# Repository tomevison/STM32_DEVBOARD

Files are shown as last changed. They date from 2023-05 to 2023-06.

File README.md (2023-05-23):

# STM32_DEVBOARD
Development board for STM32 microcontroller

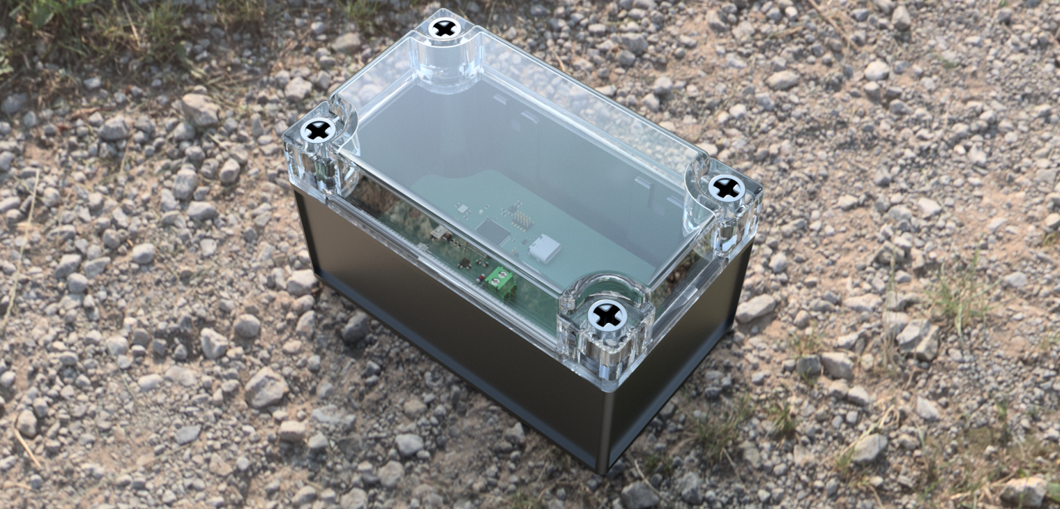
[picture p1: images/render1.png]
Render of Board in Enclosure


Board features a STM32F401RCT6 MCU with a number of peripherals.
- Temperature Humidity Pressure Sensor (Bosch BME280)
- Triple Axis Accelerometer (ST LIS2DW12)
- Tactile Button
- User LED
- USB-C COM Port
- 4-30 VDC input range

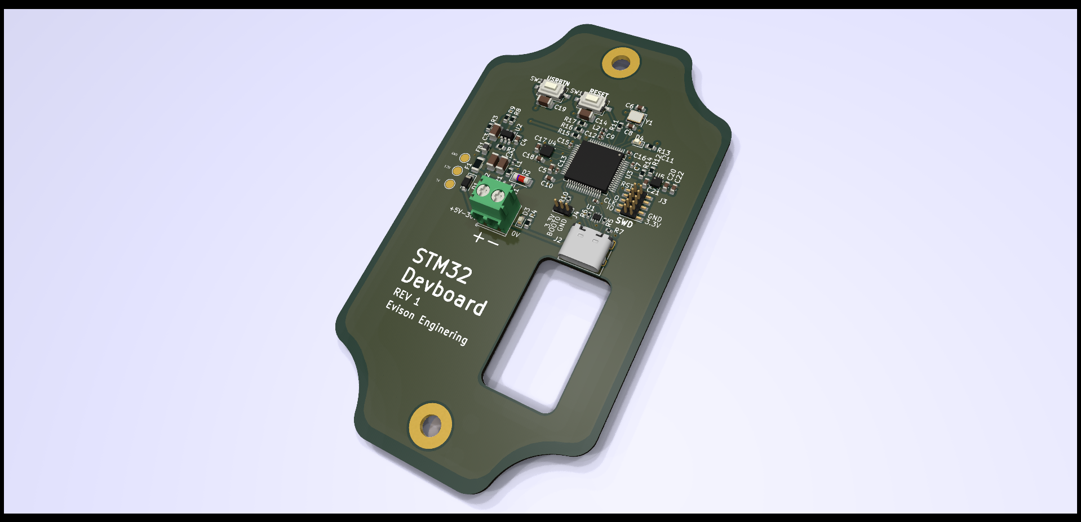
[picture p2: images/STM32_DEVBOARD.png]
Render of PCB


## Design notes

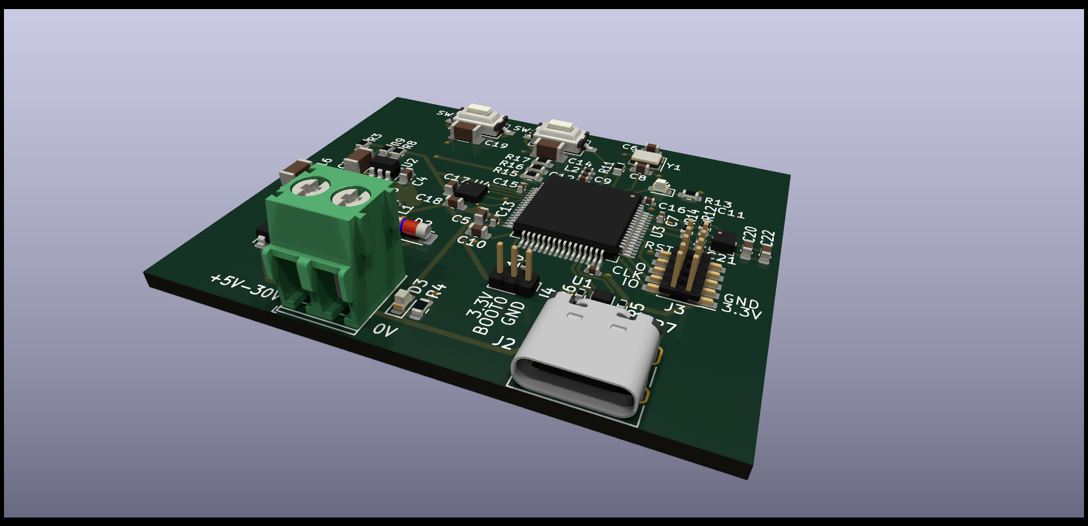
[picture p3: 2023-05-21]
images/devboard_render.png

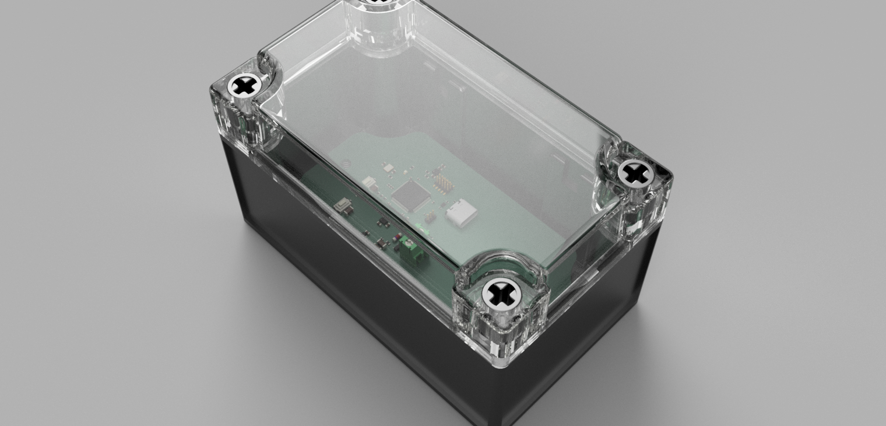
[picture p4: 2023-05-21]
images/Assemb v2.png

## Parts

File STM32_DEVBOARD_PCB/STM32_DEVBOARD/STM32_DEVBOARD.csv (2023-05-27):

# | Reference | Qty | Value | Footprint | DNP
1 | BZ1 | 1 | Buzzer | Buzzer_Beeper:MagneticBuzzer_CUI_CST-931RP-A
2 | C1, C2, C3 | 3 | 10u | Capacitor_SMD:C_1206_3216Metric
3 | C4 | 1 | 10n | Capacitor_SMD:C_0603_1608Metric
4 | C5, C10 | 2 | 4u7 | Capacitor_SMD:C_0603_1608Metric
5 | C6, C8 | 2 | 10p | Capacitor_SMD:C_0603_1608Metric
6 | C7, C11, C13, C15, C16 | 5 | 100n | Capacitor_SMD:C_0402_1005Metric
7 | C9 | 1 | 1u | Capacitor_SMD:C_0402_1005Metric
8 | C12 | 1 | 10n | Capacitor_SMD:C_0402_1005Metric
9 | C14, C19 | 2 | 0u1 | Capacitor_SMD:C_1206_3216Metric
10 | C17, C18, C20, C21 | 4 | 100n | Capacitor_SMD:C_0603_1608Metric
11 | C22 | 1 | 10u | Capacitor_SMD:C_0603_1608Metric
12 | D1 | 1 | B5819W | Diode_SMD:D_SOD-123
13 | D2 | 1 | ZMM5V6-M | Diode_SMD:D_MiniMELF
14 | D3, D4 | 2 | GRN | LED_SMD:LED_0603_1608Metric
15 | F1 | 1 | 250mA | Fuse:Fuse_1206_3216Metric
16 | FB1 | 1 | 600 @ 600MHz | Inductor_SMD:L_0805_2012Metric
17 | H1, H2 | 2 | MountingHole | MountingHole:MountingHole_4.3mm_M4_Pad
18 | J1 | 1 | Screw_Terminal_01x02 | TerminalBlock_Phoenix:TerminalBlock_Phoenix_PT-1,5-2-3.5-H_1x02_P3.50mm_Horizontal
19 | J2 | 1 | USB_C_Receptacle_USB2.0 | Connector_USB:USB_C_Receptacle_HRO_TYPE-C-31-M-12
20 | J3 | 1 | SWD | Connector_PinHeader_1.27mm:PinHeader_2x05_P1.27mm_Vertical_SMD
21 | J4 | 1 | Conn_01x03_Pin | Connector_PinHeader_1.27mm:PinHeader_1x03_P1.27mm_Vertical
22 | L1 | 1 | 4.7u | Inductor_SMD:L_0603_1608Metric
23 | L2 | 1 | 39n | Inductor_SMD:L_0402_1005Metric
24 | Q1 | 1 | AO3401A | Package_TO_SOT_SMD:SOT-23
25 | Q3 | 1 | MMBT3904 | Package_TO_SOT_SMD:SOT-23
26 | R1, R2 | 2 | 100k | Resistor_SMD:R_0603_1608Metric
27 | R3 | 1 | 68k | Resistor_SMD:R_0603_1608Metric
28 | R4, R11, R13 | 3 | R47 | Resistor_SMD:R_0603_1608Metric
29 | R5 | 1 | 1k5 | Resistor_SMD:R_0402_1005Metric
30 | R6, R7 | 2 | 5k1 | Resistor_SMD:R_0402_1005Metric
31 | R8 | 1 | 30k | Resistor_SMD:R_0603_1608Metric
32 | R9, R10, R12, R14, R17 | 5 | 10k | Resistor_SMD:R_0603_1608Metric
33 | R15 | 1 | 220k | Resistor_SMD:R_0603_1608Metric
34 | R16 | 1 | 22k | Resistor_SMD:R_0603_1608Metric
35 | R18 | 1 | 1k | Resistor_SMD:R_0603_1608Metric
36 | SW1 | 1 | BTN_RSET | STM32DEVBOARD:SW_Tactile_SPST_NO_Straight_CK_PTS636-SK25J-SMTR-LFS
37 | SW2 | 1 | BTN1 | STM32DEVBOARD:SW_Tactile_SPST_NO_Straight_CK_PTS636-SK25J-SMTR-LFS
38 | TP1 | 1 | GND | TestPoint:TestPoint_Pad_D2.0mm
39 | TP2 | 1 | 3.3V | TestPoint:TestPoint_Pad_D2.0mm
40 | TP3 | 1 | 5V | TestPoint:TestPoint_Pad_D2.0mm
41 | TP4 | 1 | 24V | TestPoint:TestPoint_Pad_D2.0mm
42 | U1 | 1 | USBLC6-2P6 | Package_TO_SOT_SMD:SOT-666
43 | U2 | 1 | TPMP2359DJ | Package_TO_SOT_SMD:SOT-23-6
44 | U3 | 1 | STM32F401RCTx | Package_QFP:LQFP-64_10x10mm_P0.5mm
45 | U4 | 1 | BME280 | Package_LGA:Bosch_LGA-8_2.5x2.5mm_P0.65mm_ClockwisePinNumbering
46 | U5 | 1 | LIS2DW12 | Package_LGA:LGA-12_2x2mm_P0.5mm
47 | Y1 | 1 | 16MHz | Crystal:Crystal_SMD_3225-4Pin_3.2x2.5mm

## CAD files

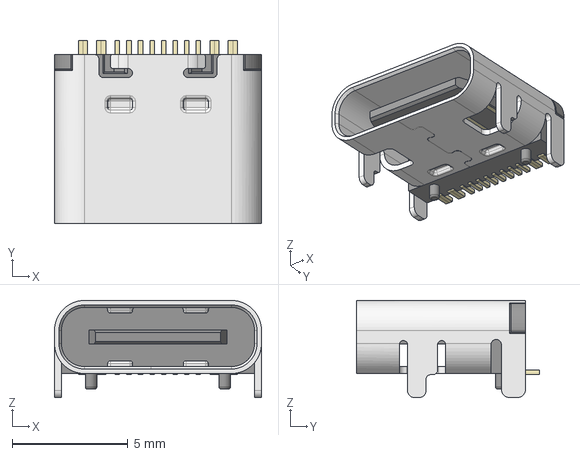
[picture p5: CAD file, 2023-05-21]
STM32_DEVBOARD_PCB/Component Models/USB_HRO_TYPE-C-31-M-12.step
8.95 x 7.90 x 4.20 mm

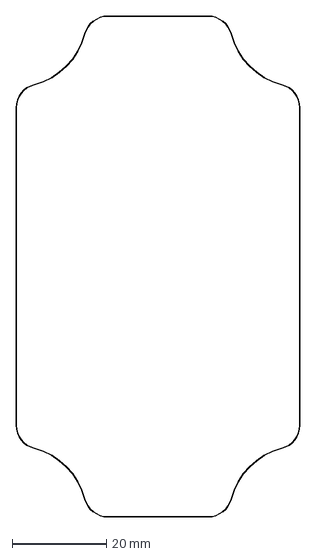
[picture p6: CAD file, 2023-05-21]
STM32_DEVBOARD_PCB/STM32_DEVBOARD/BoardOutline.dxf
60.0 x 106.0 mm

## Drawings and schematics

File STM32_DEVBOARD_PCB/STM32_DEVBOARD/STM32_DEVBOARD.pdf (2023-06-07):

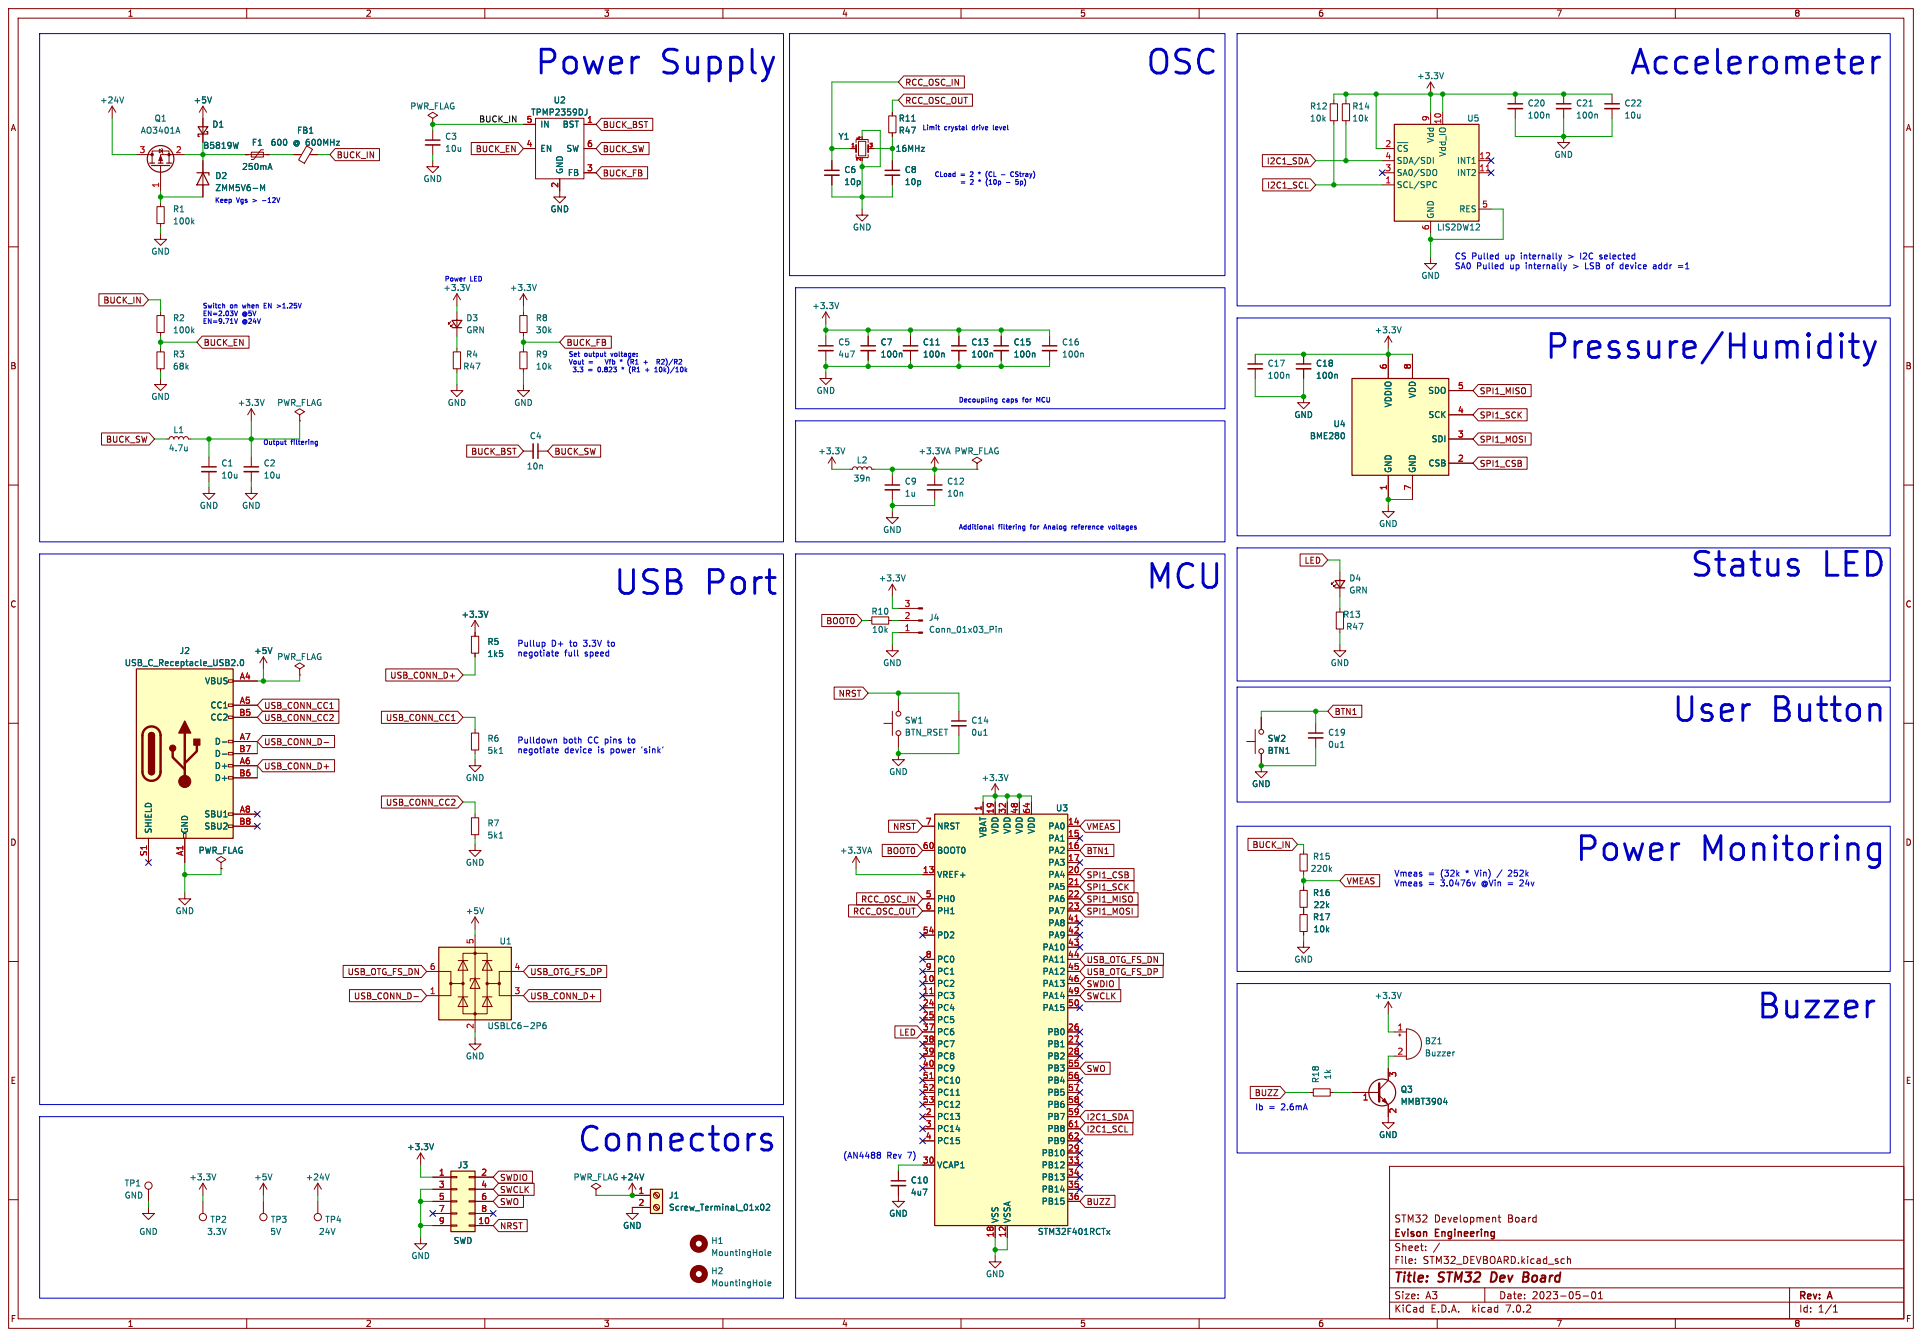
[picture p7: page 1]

BUCK_IN
Keep Vgs > -12V Output filtering Switch on when EN >1.25V

1 CSB 2 SDI 3 SCK 4 SDO 5 VDDIO

Pulldown both CC pins to

1 PC2 10 PC3 11 VSSA 12 VREF+ 13 PA0 14 PA1 15 PA2 16 PA3 17 VSS 18 VDD 19 PC13 2 PA4 20 PA5 21 PA6 22 PA7 23 PC4 24 PC5 25 PB0 26 PB1 27 PB2 28 PB10 29 PC14 3 VCAP1 30 VDD 32 PB12 33 PB13 34 PB14 35 PB15 36 PC6 37 PC7 38 PC8 39 PC15 4 PC9 40 PA8 41 PA9 42 PA10 43 PA11 44 PA12 45 PA13 46 VDD 48 PA14 49 PH0 5 PA15 50 PC10 51 PC11 52 PC12 53 PD2 54 PB3 55 PB4 56 PB5 57 PB6 58 PB7 59 PH1 6 BOOT0 60 PB8 61 PB9 62 VDD 64 NRST 7 PC0 8 PC1 9 U3 STM32F401RCTx GND

1 PC2 10 PC3 11 VSSA 12 VREF+ 13 PA0 14 PA1 15 PA2 16 PA3 17 VSS 18 VDD 19 PC13 2 PA4 20 PA5 21 PA6 22 PA7 23 PC4 24 PC5 25 PB0 26 PB1 27 PB2 28 PB10 29 PC14 3 VCAP1 30 VDD 32 PB12 33 PB13 34 PB14 35 PB15 36 PC6 37 PC7 38 PC8 39 PC15 4 PC9 40 PA8 41 PA9 42 PA10 43 PA11 44 PA12 45 PA13 46 VDD 48 PA14 49 PH0 5 PA15 50 PC10 51 PC11 52 PC12 53 PD2 54 PB3 55 PB4 56 PB5 57 PB6 58 PB7 59 PH1 6 BOOT0 60 PB8 61 PB9 62 VDD 64 NRST 7 PC0 8 PC1 9 C10

Id: 1/1 Title: STM32 Dev Board

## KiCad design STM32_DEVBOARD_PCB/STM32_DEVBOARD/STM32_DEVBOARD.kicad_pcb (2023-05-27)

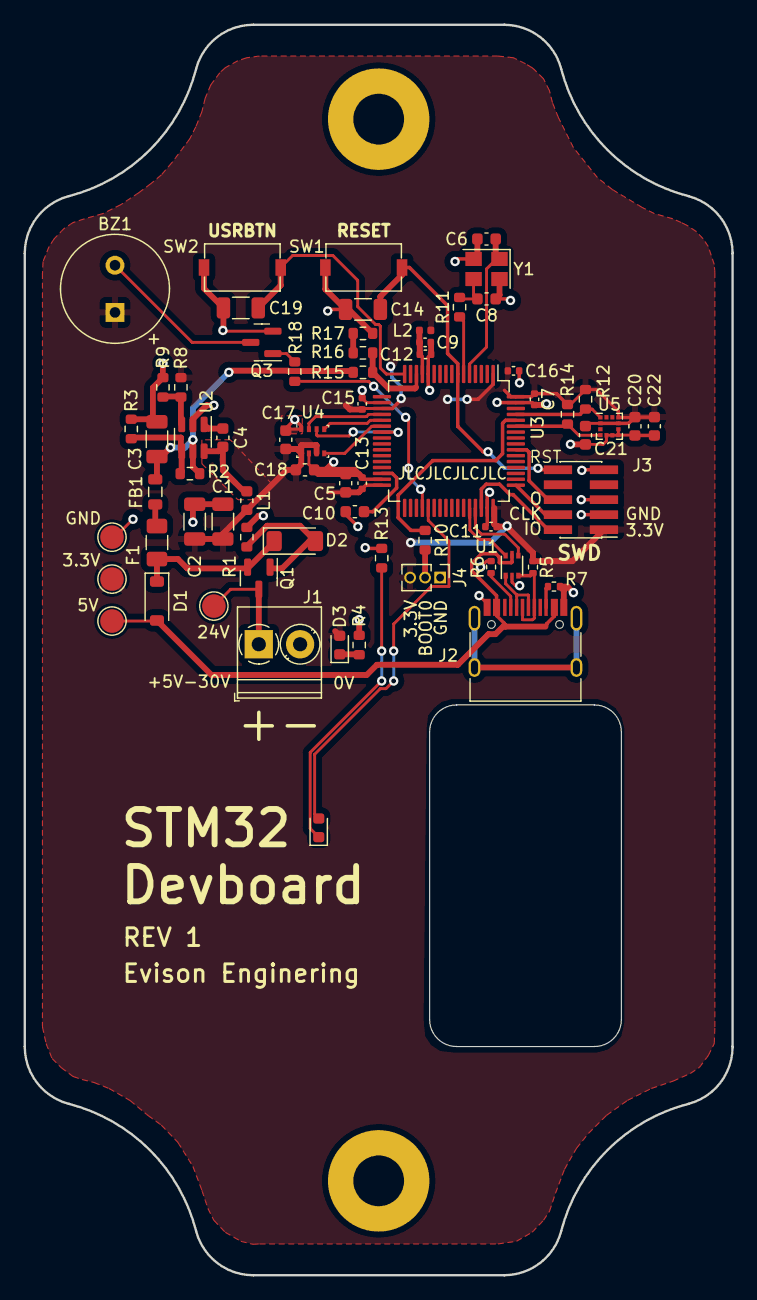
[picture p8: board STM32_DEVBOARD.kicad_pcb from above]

Board: 2 copper layers, 60.0 x 106.0 mm, 69 parts (0 on the bottom side), 44 nets.

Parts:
BZ1: Buzzer; MagneticBuzzer_CUI_CST-931RP-A
C1, C2, C3: 10u; C_1206_3216Metric
C4: 10n; C_0603_1608Metric
C5, C10: 4u7; C_0603_1608Metric
C6, C8: 10p; C_0603_1608Metric
C7, C11, C13, C15, C16: 100n; C_0402_1005Metric
C9: 1u; C_0402_1005Metric
C12: 10n; C_0402_1005Metric
C14, C19: 0u1; C_1206_3216Metric
C17, C18, C20, C21: 100n; C_0603_1608Metric
C22: 10u; C_0603_1608Metric
D1: B5819W; D_SOD-123
D2: ZMM5V6-M; D_MiniMELF
D3, D4: GRN; LED_0603_1608Metric
F1: 250mA; Fuse_1206_3216Metric
FB1: 600 @ 600MHz; L_0805_2012Metric
H1, H2: MountingHole; MountingHole_4.3mm_M4_Pad
J1: Screw_Terminal_01x02; TerminalBlock_Phoenix_PT-1,5-2-3.5-H_1x02_P3.50mm_Horizontal
J2: USB_C_Receptacle_USB2.0; USB_C_Receptacle_HRO_TYPE-C-31-M-12
J3: SWD; PinHeader_2x05_P1.27mm_Vertical_SMD
J4: Conn_01x03_Pin; PinHeader_1x03_P1.27mm_Vertical
L1: 4.7u; L_0603_1608Metric
L2: 39n; L_0402_1005Metric
Q1: AO3401A; SOT-23
Q3: MMBT3904; SOT-23
R1, R2: 100k; R_0603_1608Metric
R3: 68k; R_0603_1608Metric
R4, R11, R13: R47; R_0603_1608Metric
R5: 1k5; R_0402_1005Metric
R6, R7: 5k1; R_0402_1005Metric
R8: 30k; R_0603_1608Metric
R9, R10, R12, R14, R17: 10k; R_0603_1608Metric
R15: 220k; R_0603_1608Metric
R16: 22k; R_0603_1608Metric
R18: 1k; R_0603_1608Metric
SW1: BTN_RSET; SW_Tactile_SPST_NO_Straight_CK_PTS636-SK25J-SMTR-LFS
SW2: BTN1; SW_Tactile_SPST_NO_Straight_CK_PTS636-SK25J-SMTR-LFS
TP1: GND; TestPoint_Pad_D2.0mm
TP2: 3.3V; TestPoint_Pad_D2.0mm
TP3: 5V; TestPoint_Pad_D2.0mm
TP4: 24V; TestPoint_Pad_D2.0mm
U1: USBLC6-2P6; SOT-666
U2: TPMP2359DJ; SOT-23-6
U3: STM32F401RCTx; LQFP-64_10x10mm_P0.5mm
U4: BME280; Bosch_LGA-8_2.5x2.5mm_P0.65mm_ClockwisePinNumbering
U5: LIS2DW12; LGA-12_2x2mm_P0.5mm
Y1: 16MHz; Crystal_SMD_3225-4Pin_3.2x2.5mm

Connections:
+3.3V: BZ1.1 (-), C1.1, C2.1, C5.1, C7.1, C11.1, C13.1, C15.1, C16.1, C17.1, C18.1, C20.1, C21.1, C22.1, D3.2 (A), J3.1, J4.3, L1.2, L2.1, R5.1, R8.1, R12.1, R14.1, TP2.1, U3.1 (VBAT), U3.19 (VDD), U3.32 (VDD), U3.48 (VDD), U3.64 (VDD), U4.6 (VDDIO), U4.8 (VDD), U5.2 (~CS), U5.9 (Vdd), U5.10 (Vdd_IO)
+3.3VA: C9.1, C12.1, L2.2, U3.13 (VREF+)
+5V: D1.2 (A), J2.A4 (VBUS), J2.A9 (VBUS), J2.B4 (VBUS), J2.B9 (VBUS), TP3.1, U1.5 (VBUS)
+24V: J1.1, Q1.3 (D), TP4.1
BOOT0: R10.2, U3.60 (BOOT0)
BTN1: C19.1, SW2.2, U3.16 (PA2)
BUCK_BST: C4.2, U2.1 (BST)
BUCK_EN: R2.2, R3.1, U2.4 (EN)
BUCK_FB: R8.2, R9.1, U2.3 (FB)
BUCK_IN: C3.1, FB1.2, R2.1, R15.2, U2.5 (IN)
BUCK_SW: C4.1, L1.1, U2.6 (SW)
BUZZ: R18.2, U3.36 (PB15)
GND: C1.2, C2.2, C3.2, C5.2, C6.2, C7.2, C8.2, C9.2, C10.2, C11.2, C12.2, C13.2, C14.2, C15.2, C16.2, C17.2, C18.2, C19.2, C20.2, C21.2, C22.2, J1.2, J2.A1 (GND), J2.A12 (GND), J2.B1 (GND), J2.B12 (GND), J3.3, J3.5, J3.9, J4.1, Q3.2 (E), R1.2, R3.2, R4.1, R6.2, R7.2, R9.2, R13.1, R17.1, SW1.1, SW2.1, TP1.1, U1.2 (GND), U2.2 (GND), U3.12 (VSSA), U3.18 (VSS), U3.31 (VSS), U3.47 (VSS), U3.63 (VSS), U4.1 (GND), U4.7 (GND), U5.5 (RES), U5.6 (GND), U5.7 (GND), U5.8 (GND), Y1.2, Y1.4
I2C1_SCL: R12.2, U3.61 (PB8), U5.1 (SCL/SPC)
I2C1_SDA: R14.2, U3.59 (PB7), U5.4 (SDA/SDI)
LED: D4.2 (A), U3.37 (PC6)
NRST: C14.1, J3.10, SW1.2, U3.7 (NRST)
unnamed: BZ1.2 (+), Q3.3 (C)
unnamed: C8.1, R11.2, Y1.3
unnamed: D1.1 (K), D2.1 (K), F1.2, Q1.2 (S)
unnamed: D2.2 (A), Q1.1 (G), R1.1
unnamed: D3.1 (K), R4.2
unnamed: D4.1 (K), R13.2
unnamed: F1.1, FB1.1
unnamed: J4.2, R10.1
unnamed: Q3.1 (B), R18.1
unnamed: R16.1, R17.2
unnamed: C10.1, U3.30 (VCAP1)
RCC_OSC_IN: C6.1, U3.5 (PH0), Y1.1
RCC_OSC_OUT: R11.1, U3.6 (PH1)
SPI1_CSB: U3.20 (PA4), U4.2 (CSB)
SPI1_MISO: U3.22 (PA6), U4.5 (SDO)
SPI1_MOSI: U3.23 (PA7), U4.3 (SDI)
SPI1_SCK: U3.21 (PA5), U4.4 (SCK)
SWCLK: J3.4, U3.49 (PA14)
SWDIO: J3.2, U3.46 (PA13)
SWO: J3.6, U3.55 (PB3)
USB_CONN_CC1: J2.A5 (CC1), R6.1
USB_CONN_CC2: J2.B5 (CC2), R7.1
USB_CONN_D+: J2.A6 (D+), J2.B6 (D+), R5.2, U1.3 (I/O2)
USB_CONN_D-: J2.A7 (D-), J2.B7 (D-), U1.1 (I/O1)
USB_OTG_FS_DN: U1.6 (I/O1), U3.44 (PA11)
USB_OTG_FS_DP: U1.4 (I/O2), U3.45 (PA12)
VMEAS: R15.1, R16.2, U3.14 (PA0)

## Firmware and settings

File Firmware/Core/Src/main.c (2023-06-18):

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
/* Includes ------------------------------------------------------------------*/
#include "main.h"
#include "usb_device.h"

/* USER CODE BEGIN Includes */
#include "BME280.h"
#include "LIS2DW12.h"
#include "PIEZO.h"

/* USER CODE END Includes */

ADC_HandleTypeDef hadc1;

I2C_HandleTypeDef hi2c1;

SPI_HandleTypeDef hspi1;

TIM_HandleTypeDef htim1;

/* USER CODE BEGIN PV */
BME280 bme;
LIS2 lis;

/* USER CODE END PV */

void SystemClock_Config(void);
static void MX_GPIO_Init(void);
static void MX_ADC1_Init(void);
static void MX_I2C1_Init(void);
static void MX_SPI1_Init(void);
static void MX_TIM1_Init(void);
/* USER CODE BEGIN 0 */
double delay = 20;

/* USER CODE END 0 */

/**
  * @brief  The application entry point.
  * @retval int
  */
int main(void)
{
  /* MCU Configuration--------------------------------------------------------*/

  /* Reset of all peripherals, Initializes the Flash interface and the Systick. */
  HAL_Init();

  /* Configure the system clock */
  SystemClock_Config();

  /* Initialize all configured peripherals */
  MX_GPIO_Init();
  MX_ADC1_Init();
  MX_I2C1_Init();
  MX_SPI1_Init();
  MX_USB_DEVICE_Init();
  MX_TIM1_Init();
  /* USER CODE BEGIN 2 */
  uint32_t adc_val;
  double VMEAS, VIN;
  int running = 0;

  //BME280_Init(&bme, &hspi1, SPI1_CSB_GPIO_Port, SPI1_CSB_Pin);
  LIS2_Init(&lis, &hi2c1);
  //HAL_TIM_PWM_Start(&htim1,TIM_CHANNEL_3);
  //HAL_TIMEx_PWMN_Start(&htim1, TIM_CHANNEL_3);


  /* USER CODE END 2 */

  /* Infinite loop */
  /* USER CODE BEGIN WHILE */
  while (1){
	  // read input voltage
//	  HAL_ADC_Start(&hadc1); // start the adc
//	  HAL_ADC_PollForConversion(&hadc1, 100); // poll for conversion
//
//	  adc_val = HAL_ADC_GetValue(&hadc1); // get the adc value
//	  VMEAS = (adc_val/4096.0)*3.2;
//	  VIN = (252.0*VMEAS)/32.0;
//
//	  HAL_ADC_Stop(&hadc1); // stop adc

	  //BME280_updateValues(&bme);
	  if(!HAL_GPIO_ReadPin(BTN1_GPIO_Port, BTN1_Pin)){
		  if(!running){
			  running = 1;
			  HAL_TIM_PWM_Start(&htim1,TIM_CHANNEL_3);
			  HAL_TIMEx_PWMN_Start(&htim1, TIM_CHANNEL_3);
		  }
	  }else{
		  if(running){
			  running = 0;
			  HAL_TIM_PWM_Stop(&htim1,TIM_CHANNEL_3);
			  HAL_TIMEx_PWMN_Stop(&htim1, TIM_CHANNEL_3);
		  }
	  }
	  LIS2_Refresh(&lis);
	  PIEZO_setHz(lis.accZ, &htim1);
	  HAL_Delay(100);

    /* USER CODE END WHILE */

    /* USER CODE BEGIN 3 */
  }
  /* USER CODE END 3 */
}

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


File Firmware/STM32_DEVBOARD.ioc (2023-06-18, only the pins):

Mcu.UserName=STM32F401RCTx
PA0-WKUP.GPIO_Label=VMEAS
PA0-WKUP.Signal=ADCx_IN0
PA11.Signal=USB_OTG_FS_DM
PA12.Signal=USB_OTG_FS_DP
PA13.Signal=SYS_JTMS-SWDIO
PA14.Signal=SYS_JTCK-SWCLK
PA2.GPIO_Label=BTN1
PA2.Signal=GPIO_Input
PA4.GPIO_Label=SPI1_CSB
PA4.Signal=GPIO_Output
PA5.Signal=SPI1_SCK
PA6.Signal=SPI1_MISO
PA7.Signal=SPI1_MOSI
PB15.Signal=TIM1_CH3N
PB3.Signal=SYS_JTDO-SWO
PB7.Signal=I2C1_SDA
PB8.Signal=I2C1_SCL
PC6.GPIO_Label=LED
PC6.Signal=GPIO_Output

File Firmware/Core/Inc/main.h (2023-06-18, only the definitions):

#define VMEAS_Pin GPIO_PIN_0
#define VMEAS_GPIO_Port GPIOA
#define BTN1_Pin GPIO_PIN_2
#define BTN1_GPIO_Port GPIOA
#define SPI1_CSB_Pin GPIO_PIN_4
#define SPI1_CSB_GPIO_Port GPIOA
#define LED_Pin GPIO_PIN_6
#define LED_GPIO_Port GPIOC

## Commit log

2023-05-02 Update symbols and check USB
    [STM32_DEVBOARD.kicad_sch]
2023-05-16 Added USB C connector and tidy up traces.
    [STM32_DEVBOARD.csv, STM32_DEVBOARD.kicad_pcb]
2023-05-17 Added images and more tidy of PCB
    [STM32_DEVBOARD.kicad_pcb]
2023-05-21 Added images of render
    [BoardOutline.dxf, STM32_DEVBOARD.kicad_pcb, STM32_DEVBOARD.kicad_sch]
2023-05-21 Added images
    [USB_HRO_TYPE-C-31-M-12.step]
2023-05-21 Upgrade picture quality
    [STM32_DEVBOARD.kicad_pcb]
2023-05-22 Updates to board and start to populate BOM
    [STM32_DEVBOARD.kicad_pcb, STM32_DEVBOARD.kicad_sch]
2023-05-23 Added PCB render
    [STM32_DEVBOARD.kicad_sch]
2023-05-23 Add pdf schematic
2023-05-23 Add plot of PCB
2023-05-24 Remove files
    [STM32_DEVBOARD.csv, STM32_DEVBOARD.kicad_pcb, STM32_DEVBOARD.kicad_sch]
2023-05-24 i think its working
    [STM32_DEVBOARD.kicad_pcb]
2023-06-07 updated firmware examples
    [Calculations.xlsx, STM32_DEVBOARD.kicad_sch]

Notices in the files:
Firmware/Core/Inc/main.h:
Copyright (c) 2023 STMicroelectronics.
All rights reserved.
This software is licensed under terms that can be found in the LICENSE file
